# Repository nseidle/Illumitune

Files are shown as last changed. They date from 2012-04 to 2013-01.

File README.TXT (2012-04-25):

Illumitune is a exhibit at a kid's museum that has 8 infrared channels. When a channel is broken, a light turns on and a tone is played.

More information can be found at: http://www.sparkfun.com/tutorials/282

This repository contains all the firmware and design files for the various parts of the electronics. It also contains the logs from various dates. These logs show the usage information and are used for debugging and use trends.

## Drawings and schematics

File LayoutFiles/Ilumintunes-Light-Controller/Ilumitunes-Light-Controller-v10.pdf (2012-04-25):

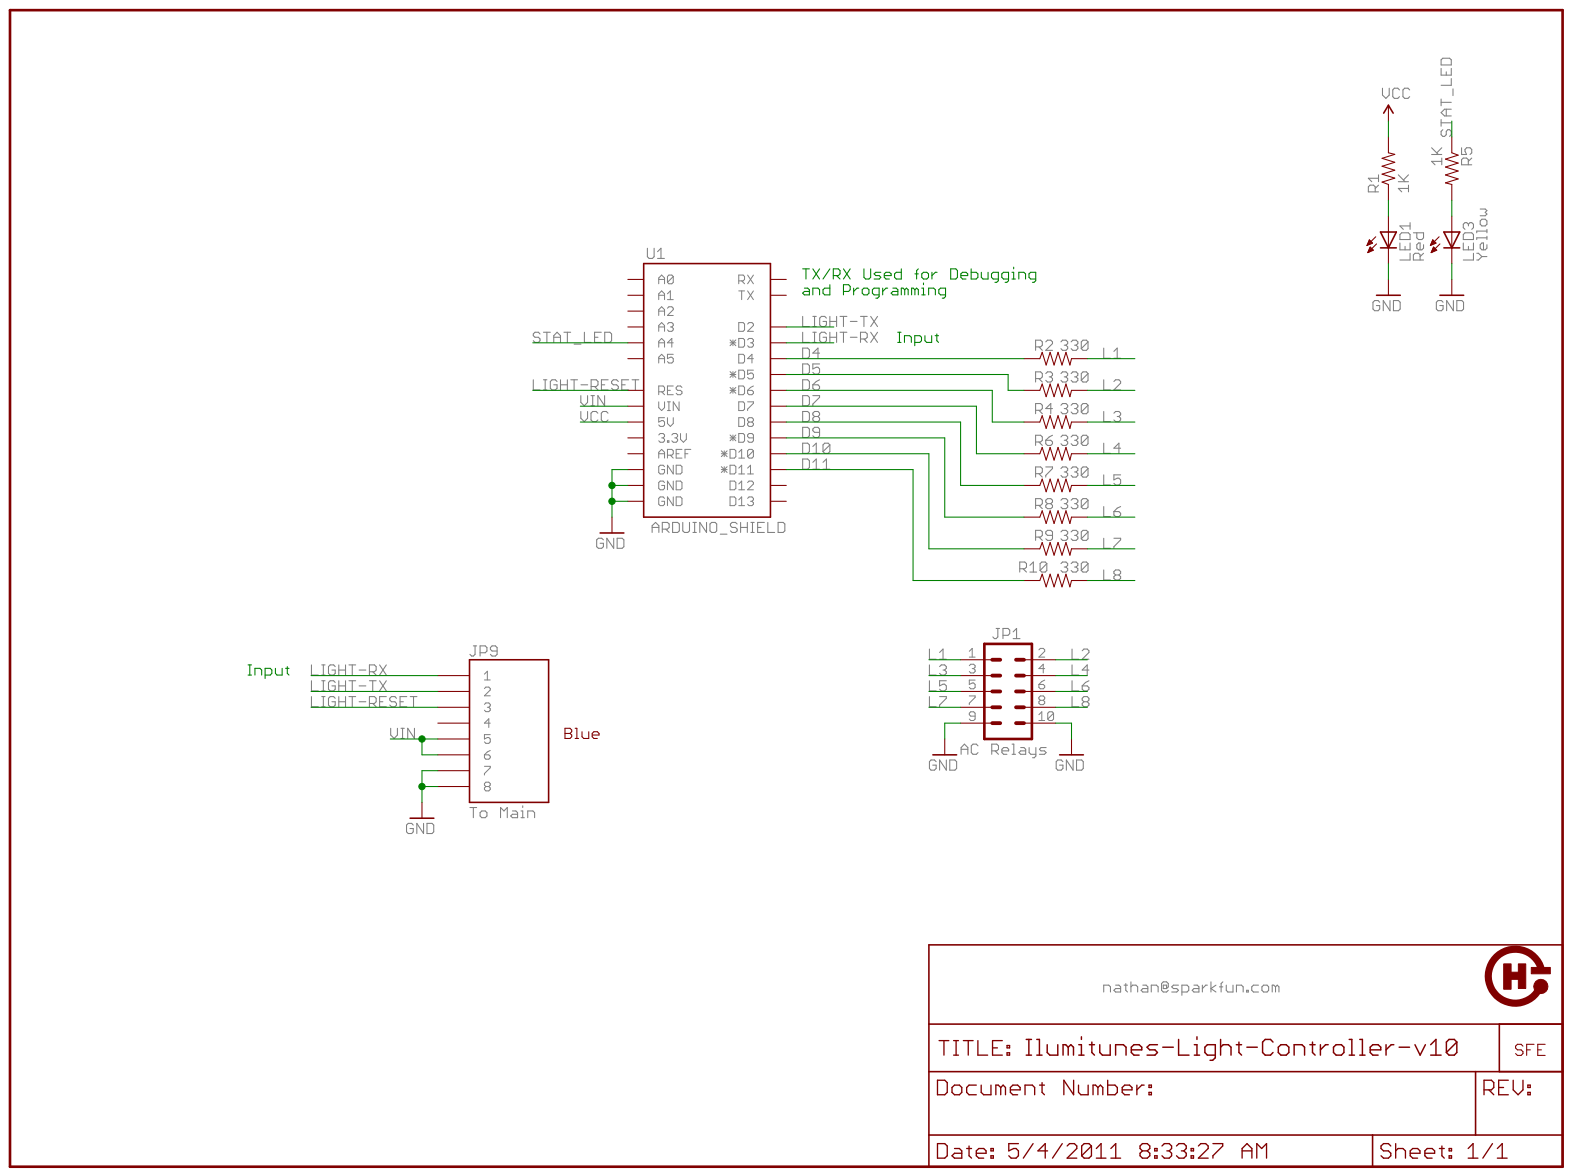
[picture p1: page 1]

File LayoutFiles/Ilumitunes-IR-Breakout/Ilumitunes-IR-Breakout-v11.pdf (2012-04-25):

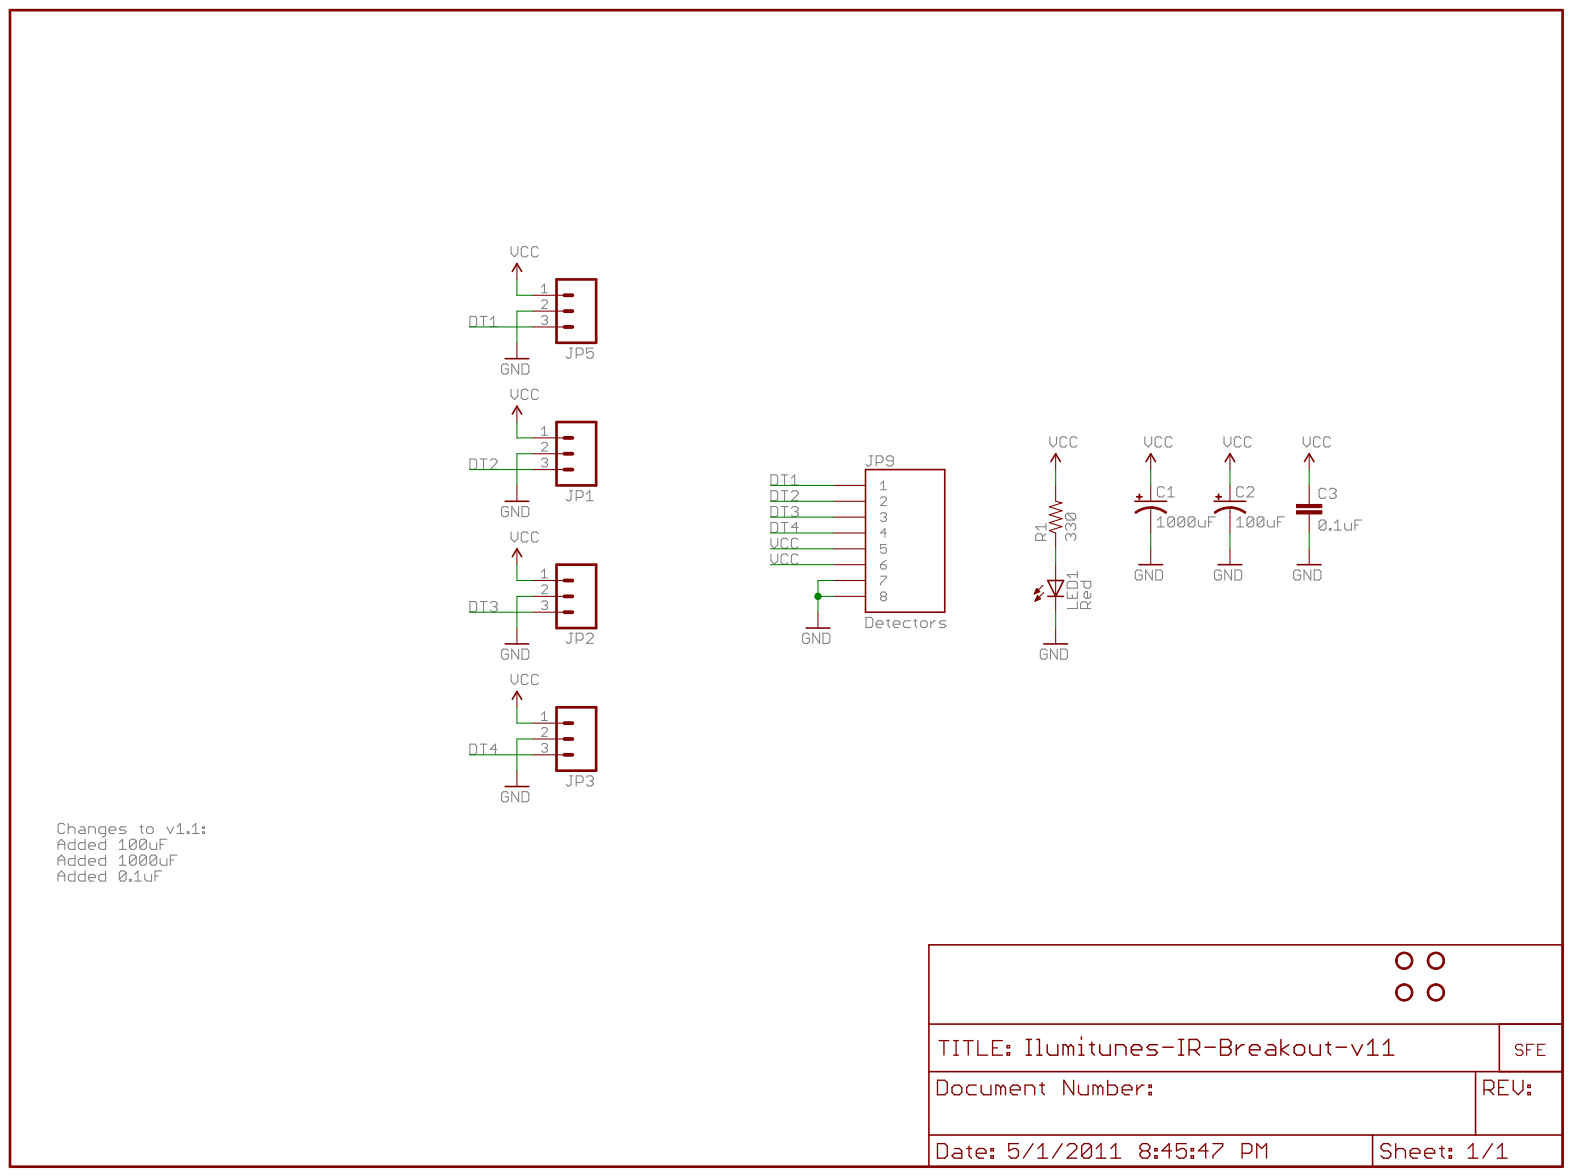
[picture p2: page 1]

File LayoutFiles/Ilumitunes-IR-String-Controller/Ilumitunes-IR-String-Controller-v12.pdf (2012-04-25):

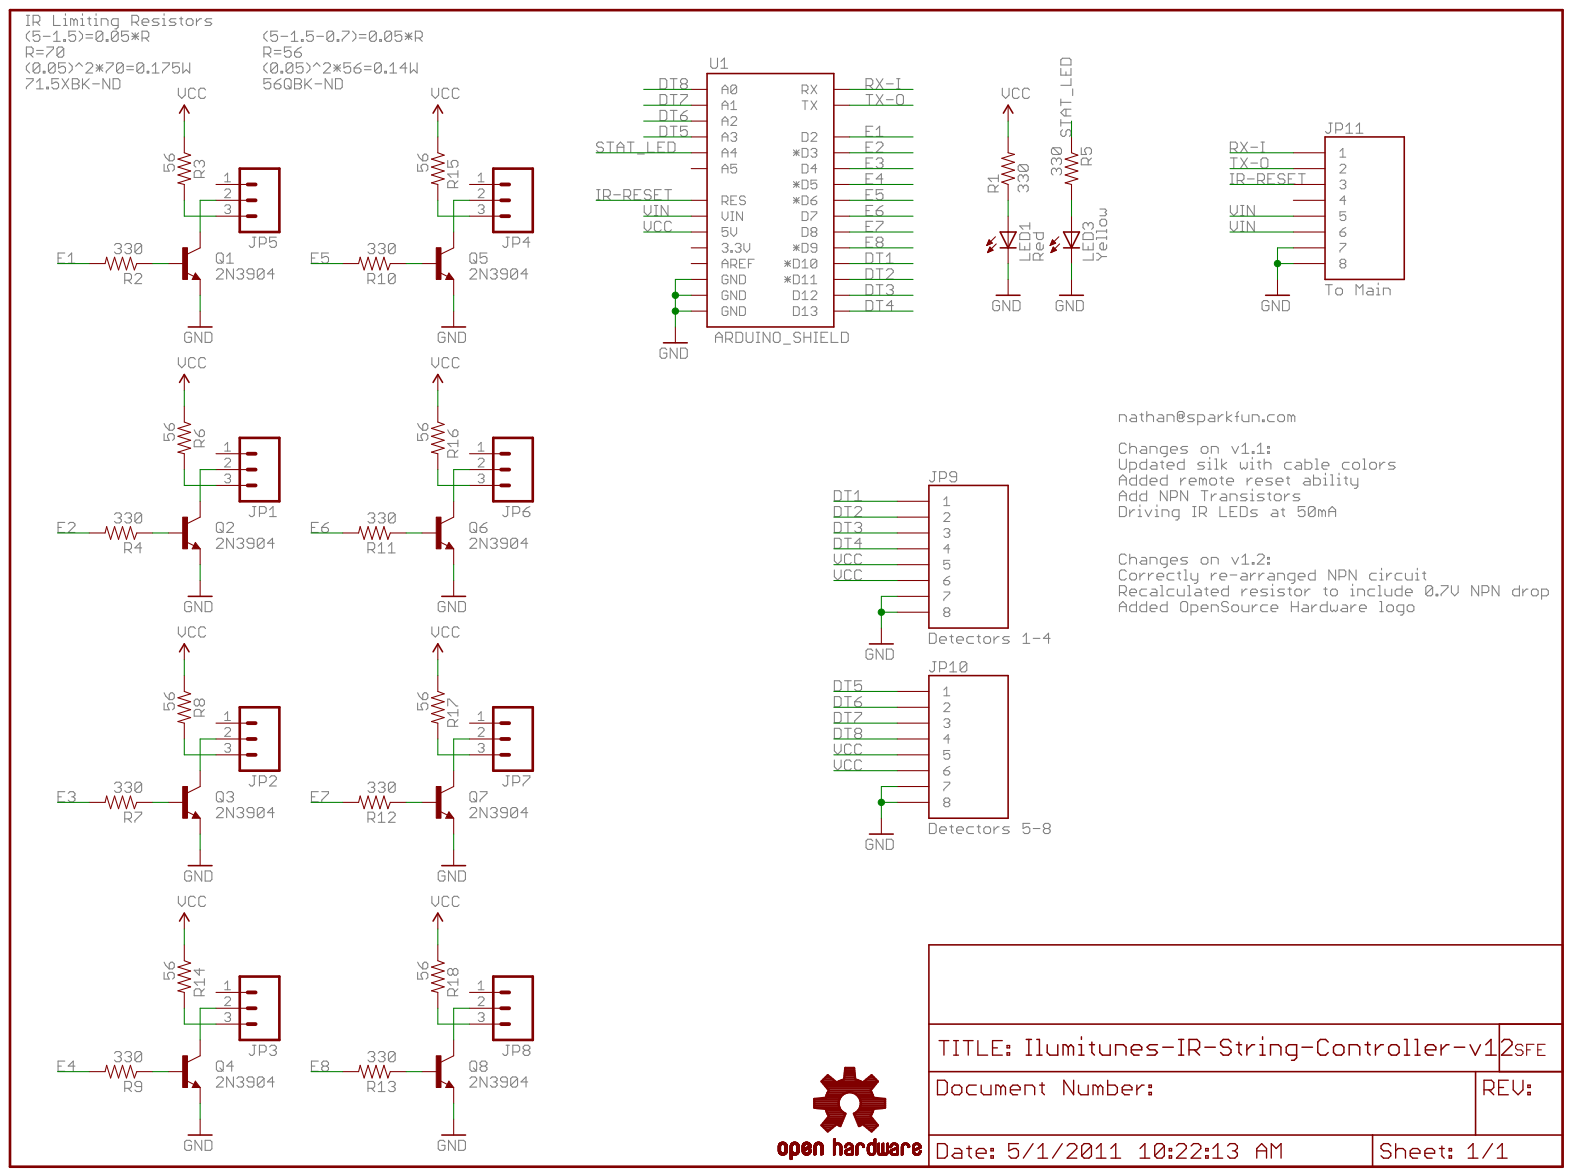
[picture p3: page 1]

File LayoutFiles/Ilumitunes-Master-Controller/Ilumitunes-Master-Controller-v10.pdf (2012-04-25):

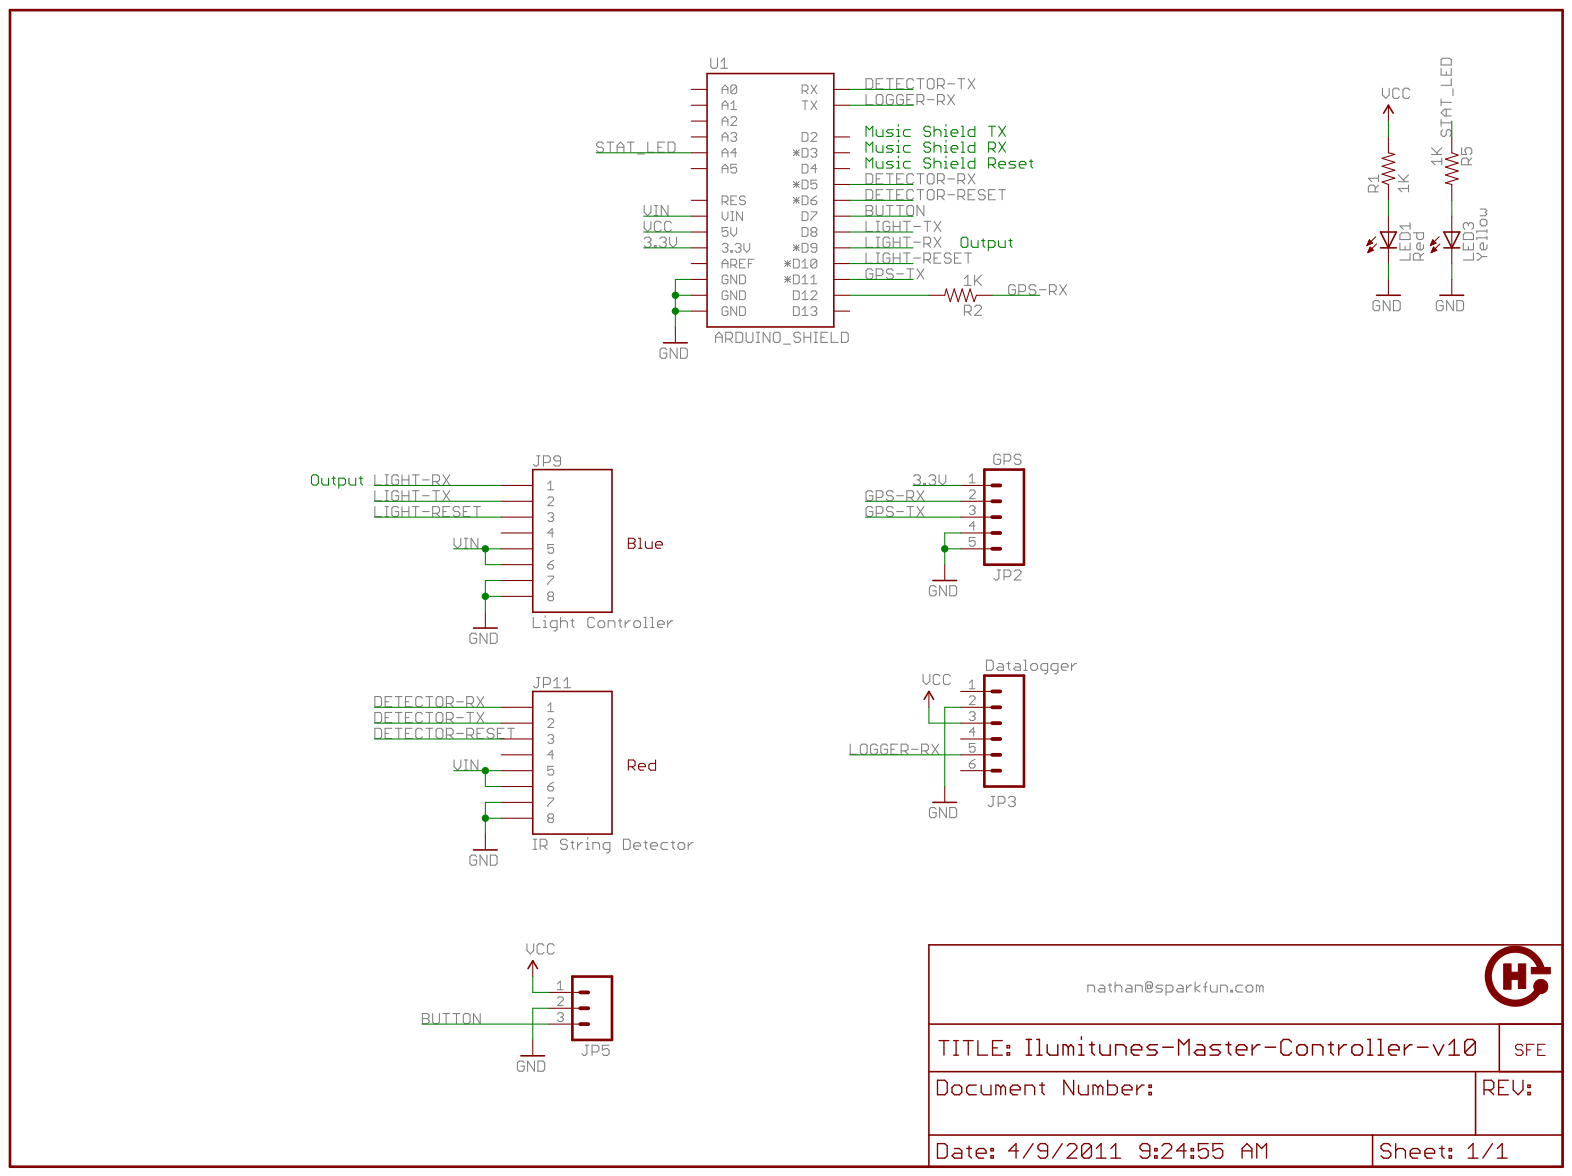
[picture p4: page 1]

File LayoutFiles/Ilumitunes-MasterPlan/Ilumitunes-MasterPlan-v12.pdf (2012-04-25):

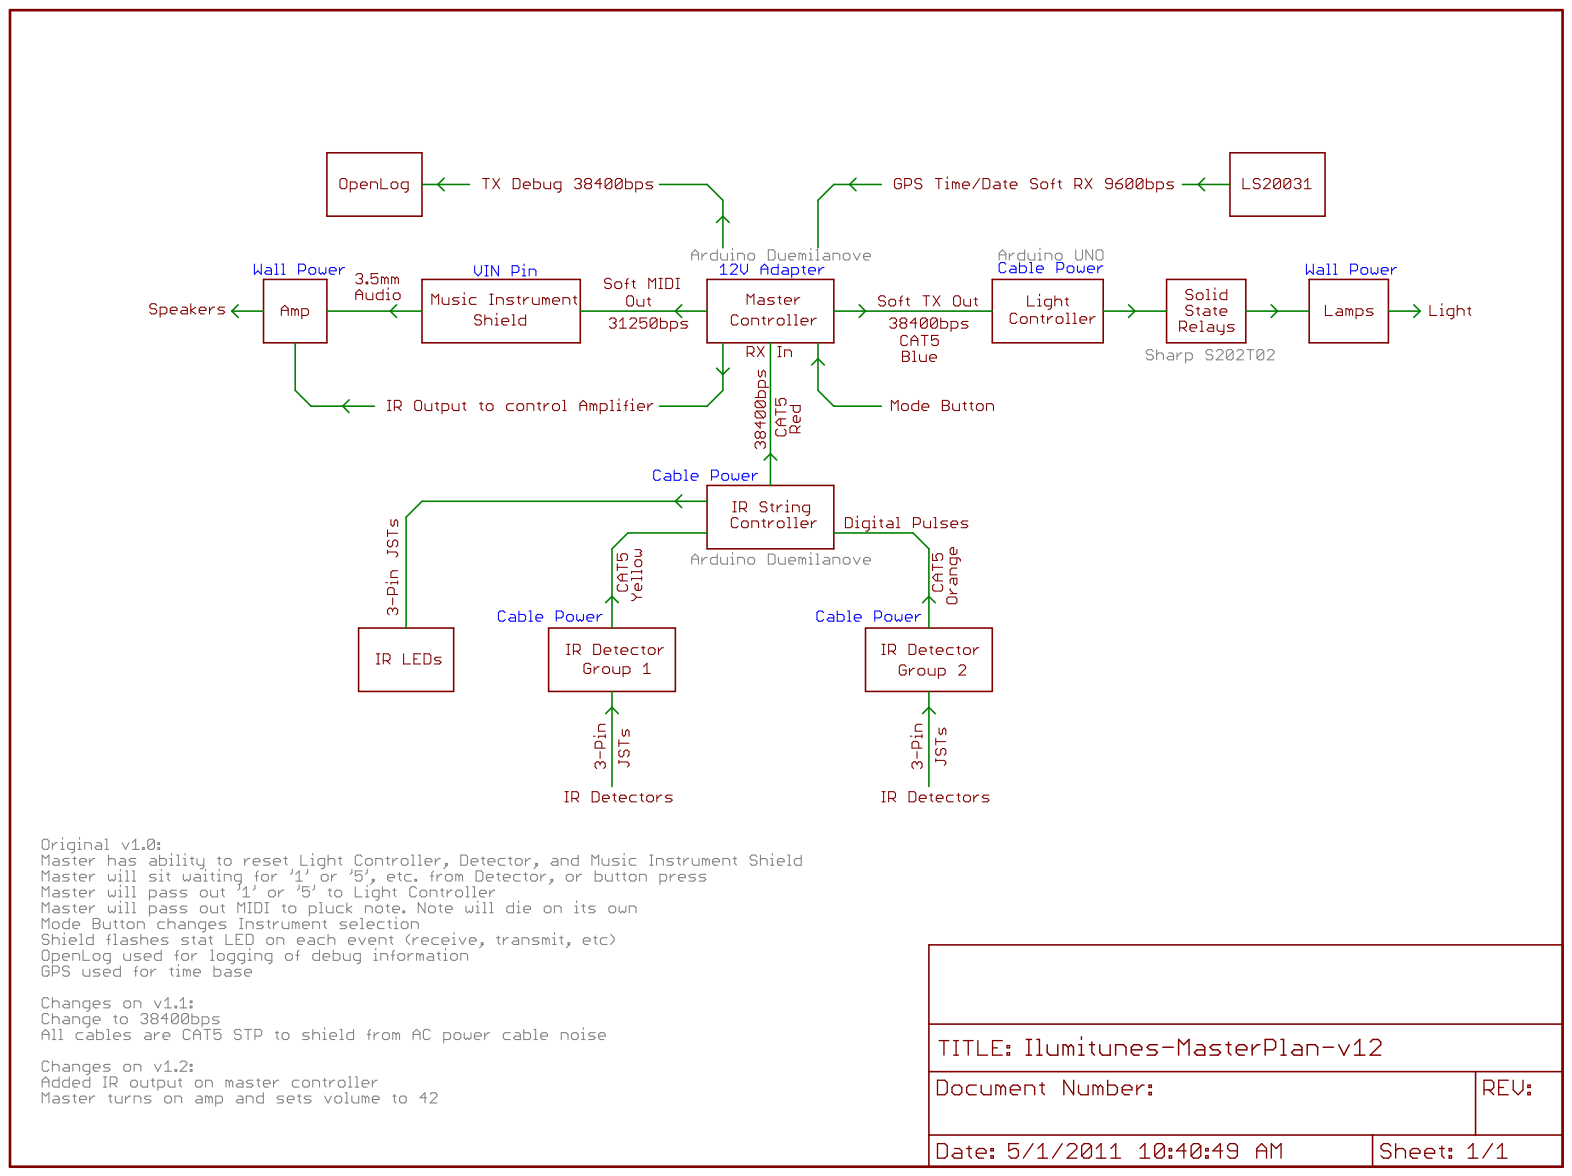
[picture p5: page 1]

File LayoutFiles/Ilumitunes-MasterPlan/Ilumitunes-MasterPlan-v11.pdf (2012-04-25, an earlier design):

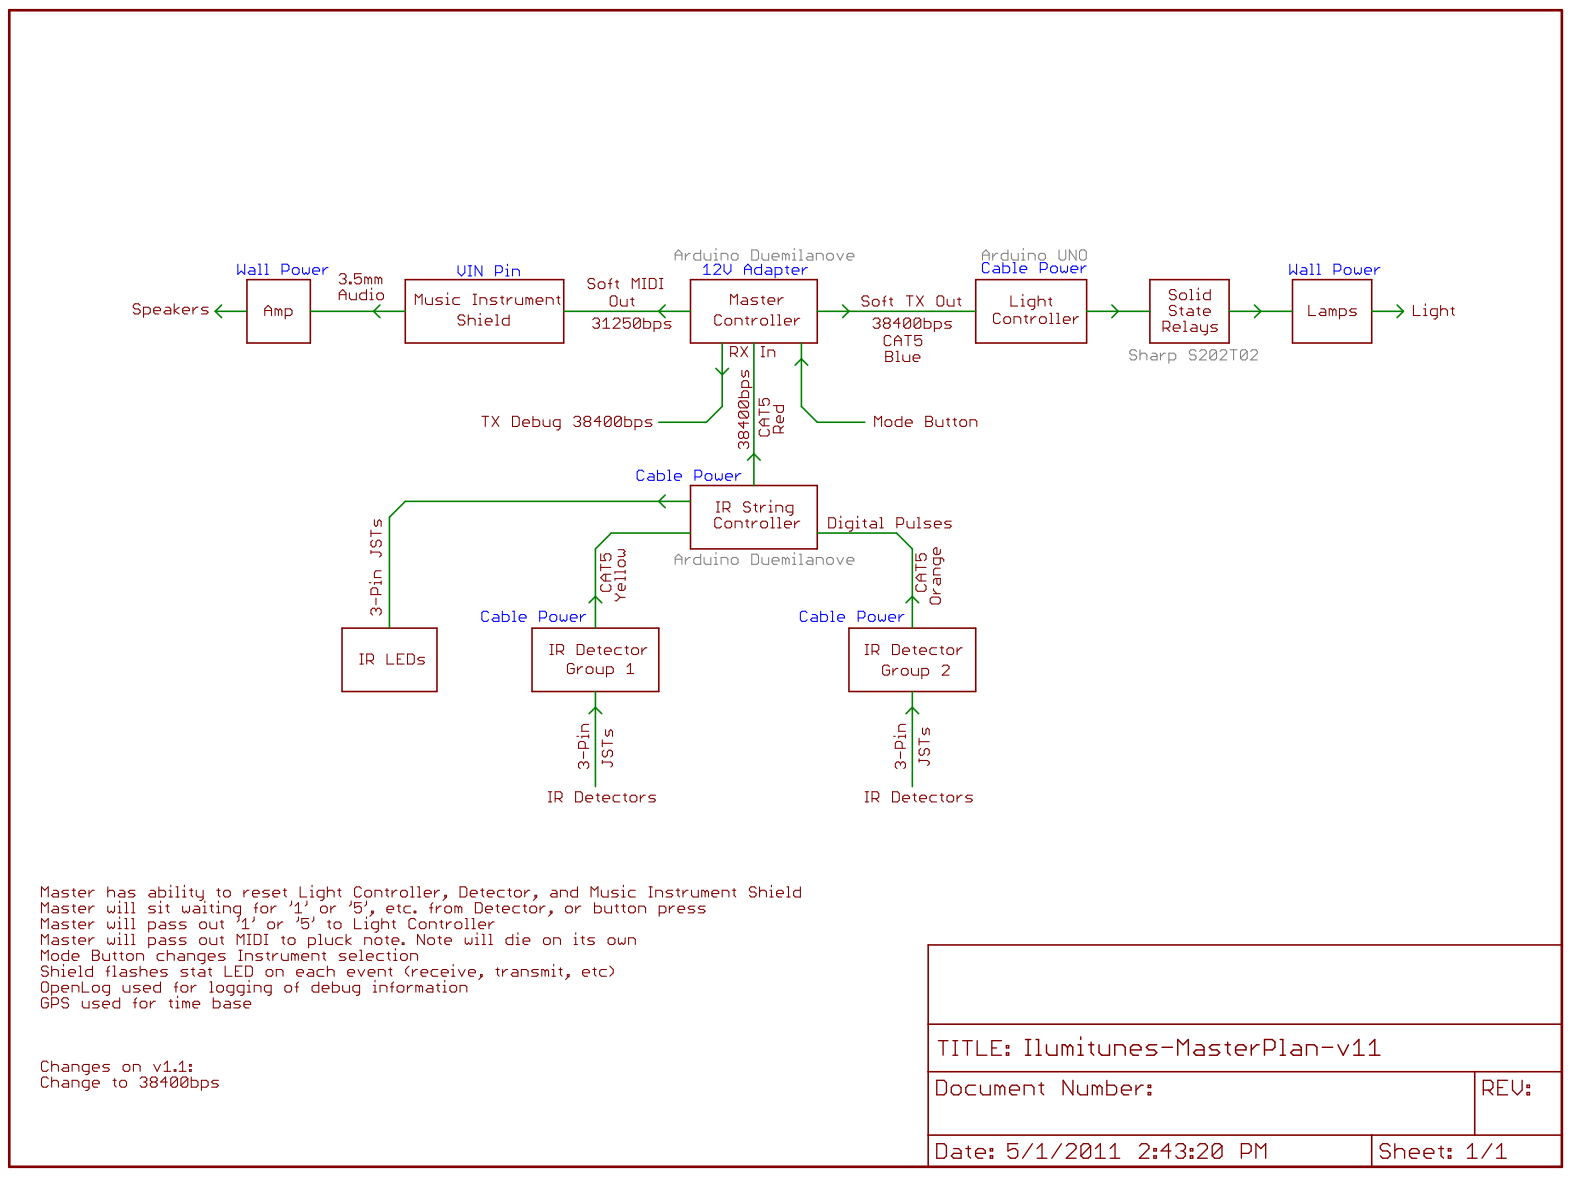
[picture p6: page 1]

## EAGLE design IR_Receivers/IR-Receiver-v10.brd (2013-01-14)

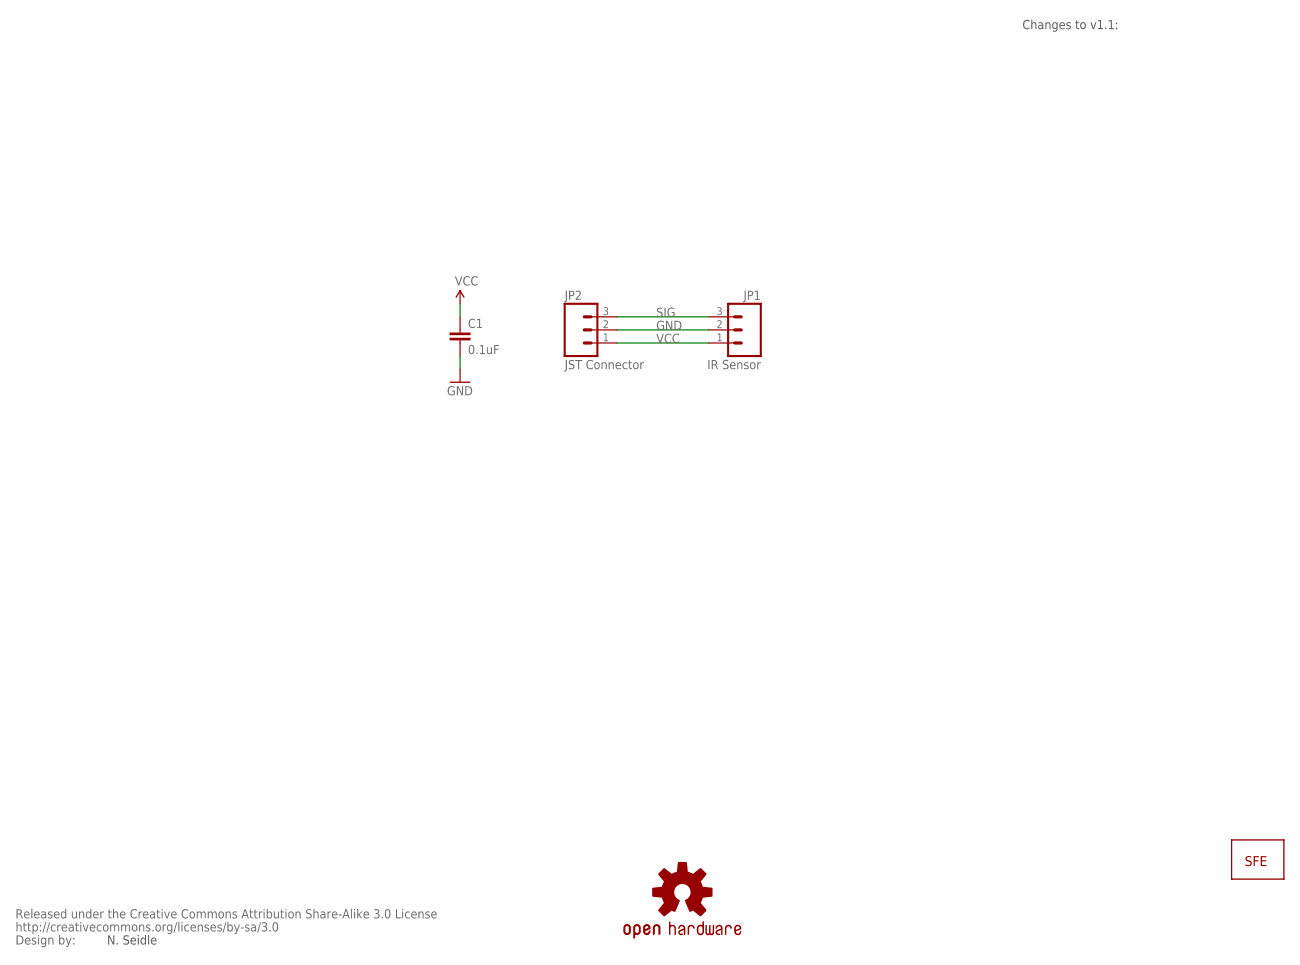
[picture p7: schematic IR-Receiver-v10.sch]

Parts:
C1: 0.1uF; CAP-PTH-SMALL2
JP1: IR Sensor; 1X03
JP2: JST Connector; JST-3-PTH
U$1: LOGO-SFESK; SFE-LOGO-FLAME
U$2: CREATIVE_COMMONS
U$4: OSHW-LOGOS; OSHW-LOGO-S

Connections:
GND: C1.2, JP1.2, JP2.2
SIG: JP1.3, JP2.3
VCC: C1.1, JP1.1, JP2.1

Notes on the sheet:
N. Seidle
Changes to v1.1:

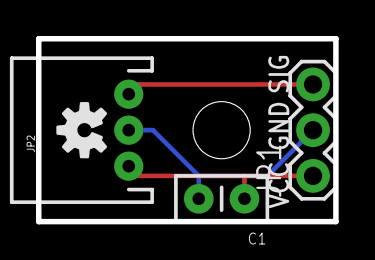
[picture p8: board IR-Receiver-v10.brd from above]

Board: 2 copper layers, 16.5 x 10.2 mm, 6 parts (1 on the bottom side), 3 nets.

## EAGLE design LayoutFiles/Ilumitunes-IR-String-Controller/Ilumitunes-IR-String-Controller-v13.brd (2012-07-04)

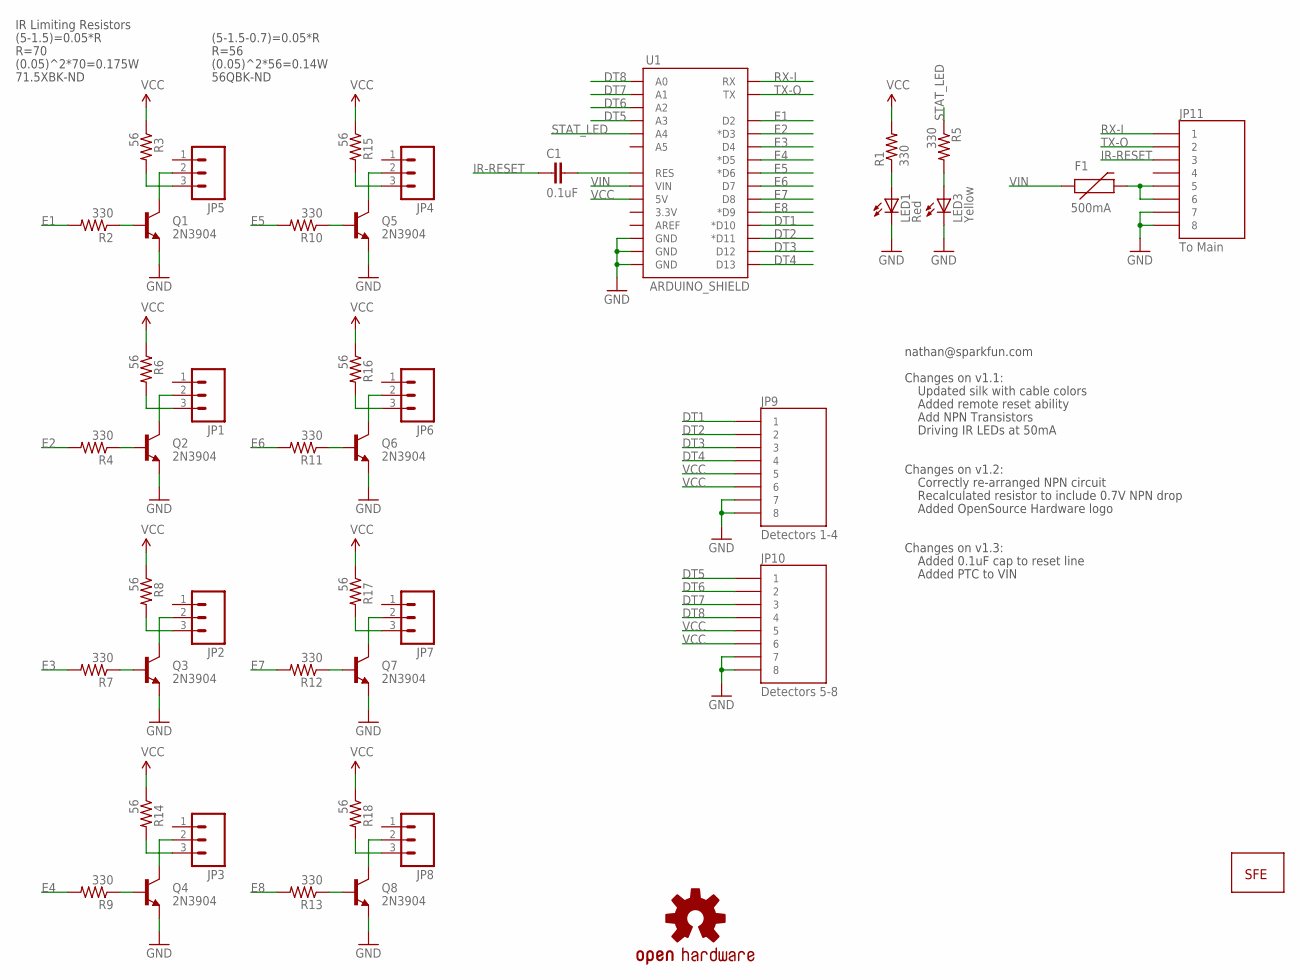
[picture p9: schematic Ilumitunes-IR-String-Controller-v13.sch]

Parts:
C1: 0.1uF; CAP-PTH-SMALL2
F1: 500mA; PTC
JP1, JP2, JP3, JP4, JP5, JP6, JP7, JP8: M03JST-PTH-VERT; JST-3-PTH-VERT
JP9: Detectors 1-4; RJ45-8
JP10: Detectors 5-8; RJ45-8
JP11: To Main; RJ45-8
LED1: Red; LED5MM
LED3: Yellow; LED5MM
Q1, Q2, Q3, Q4, Q5, Q6, Q7, Q8: 2N3904; TO-92
R1, R2, R4, R5, R7, R9, R10, R11, R12, R13: 330; AXIAL-0.3
R3, R6, R8, R14, R15, R16, R17, R18: 56; AXIAL-0.3
U1: ARDUINO_SHIELD; DUEMILANOVE_SHIELD_NOHOLES
U$1: LOGO-SFENEW; SFE-NEW-WEBLOGO
U$3: OSHW-LOGOS; OSHW-LOGO-S

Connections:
DT1: JP9.1, U1.D10 (*D10)
DT2: JP9.2, U1.D11 (*D11)
DT3: JP9.3, U1.D12
DT4: JP9.4, U1.D13
DT5: JP10.1, U1.A3
DT6: JP10.2, U1.A2
DT7: JP10.3, U1.A1
DT8: JP10.4, U1.A0
E1: R2.P$2 (2), U1.D2
E2: R4.P$2 (2), U1.D3 (*D3)
E3: R7.P$2 (2), U1.D4
E4: R9.P$2 (2), U1.D5 (*D5)
E5: R10.P$2 (2), U1.D6 (*D6)
E6: R11.P$2 (2), U1.D7
E7: R12.P$2 (2), U1.D8
E8: R13.P$2 (2), U1.D9 (*D9)
GND: JP9.7, JP9.8, JP10.7, JP10.8, JP11.7, JP11.8, LED1.K (C), LED3.K (C), Q1.1 (E), Q2.1 (E), Q3.1 (E), Q4.1 (E), Q5.1 (E), Q6.1 (E), Q7.1 (E), Q8.1 (E), U1.GND@0 (GND), U1.GND@1 (GND), U1.GND@2 (GND)
IR-RESET: C1.1, JP11.3
unnamed: LED1.A, R1.P$1 (1)
unnamed: Q1.2 (B), R2.P$1 (1)
unnamed: JP5.2, Q1.3 (C)
unnamed: LED3.A, R5.P$2 (2)
unnamed: JP5.3, R3.P$2 (2)
unnamed: JP1.2, Q2.3 (C)
unnamed: JP3.2, Q4.3 (C)
unnamed: JP8.2, Q8.3 (C)
unnamed: Q2.2 (B), R4.P$1 (1)
unnamed: JP1.3, R6.P$2 (2)
unnamed: Q3.2 (B), R7.P$1 (1)
unnamed: Q4.2 (B), R9.P$1 (1)
unnamed: Q6.2 (B), R11.P$1 (1)
unnamed: JP4.2, Q5.3 (C)
unnamed: JP6.3, R16.P$2 (2)
unnamed: Q7.2 (B), R12.P$1 (1)
unnamed: JP2.3, R8.P$2 (2)
unnamed: JP3.3, R14.P$2 (2)
unnamed: Q5.2 (B), R10.P$1 (1)
unnamed: C1.2, U1.RES
unnamed: JP4.3, R15.P$2 (2)
unnamed: JP6.2, Q6.3 (C)
unnamed: JP7.3, R17.P$2 (2)
unnamed: Q8.2 (B), R13.P$1 (1)
unnamed: JP7.2, Q7.3 (C)
unnamed: JP8.3, R18.P$2 (2)
unnamed: JP2.2, Q3.3 (C)
unnamed: F1.P$2 (2), JP11.5, JP11.6
RX-I: JP11.1, U1.RX
STAT_LED: R5.P$1 (1), U1.A4
TX-O: JP11.2, U1.TX
VCC: JP9.5, JP9.6, JP10.5, JP10.6, R1.P$2 (2), R3.P$1 (1), R6.P$1 (1), R8.P$1 (1), R14.P$1 (1), R15.P$1 (1), R16.P$1 (1), R17.P$1 (1), R18.P$1 (1), U1.5V
VIN: F1.P$1 (1), U1.VIN

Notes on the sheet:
Changes on v1.1:
Updated silk with cable colors
Added remote reset ability
nathan@sparkfun.com
Add NPN Transistors
(5-1.5)=0.05*R
R=70
(0.05)^2*70=0.175W
71.5XBK-ND
Driving IR LEDs at 50mA
IR Limiting Resistors
(5-1.5-0.7)=0.05*R
R=56
(0.05)^2*56=0.14W
56QBK-ND
Changes on v1.2:
Correctly re-arranged NPN circuit
Recalculated resistor to include 0.7V NPN drop
Added OpenSource Hardware logo
Changes on v1.3:
Added 0.1uF cap to reset line
Added PTC to VIN

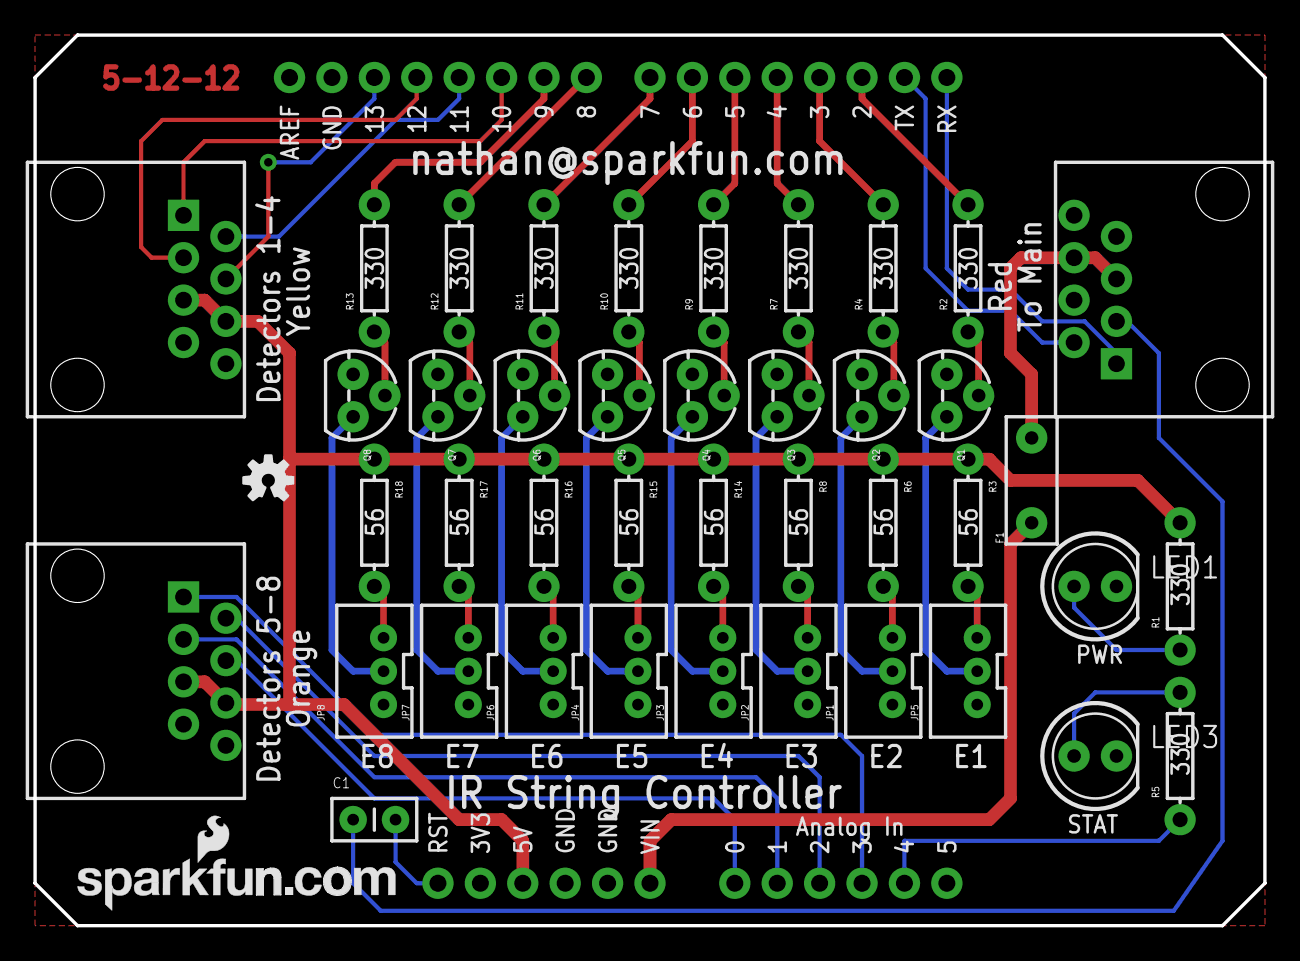
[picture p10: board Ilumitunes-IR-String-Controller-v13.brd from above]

Board: 2 copper layers, 73.7 x 53.3 mm, 44 parts (0 on the bottom side), 51 nets.

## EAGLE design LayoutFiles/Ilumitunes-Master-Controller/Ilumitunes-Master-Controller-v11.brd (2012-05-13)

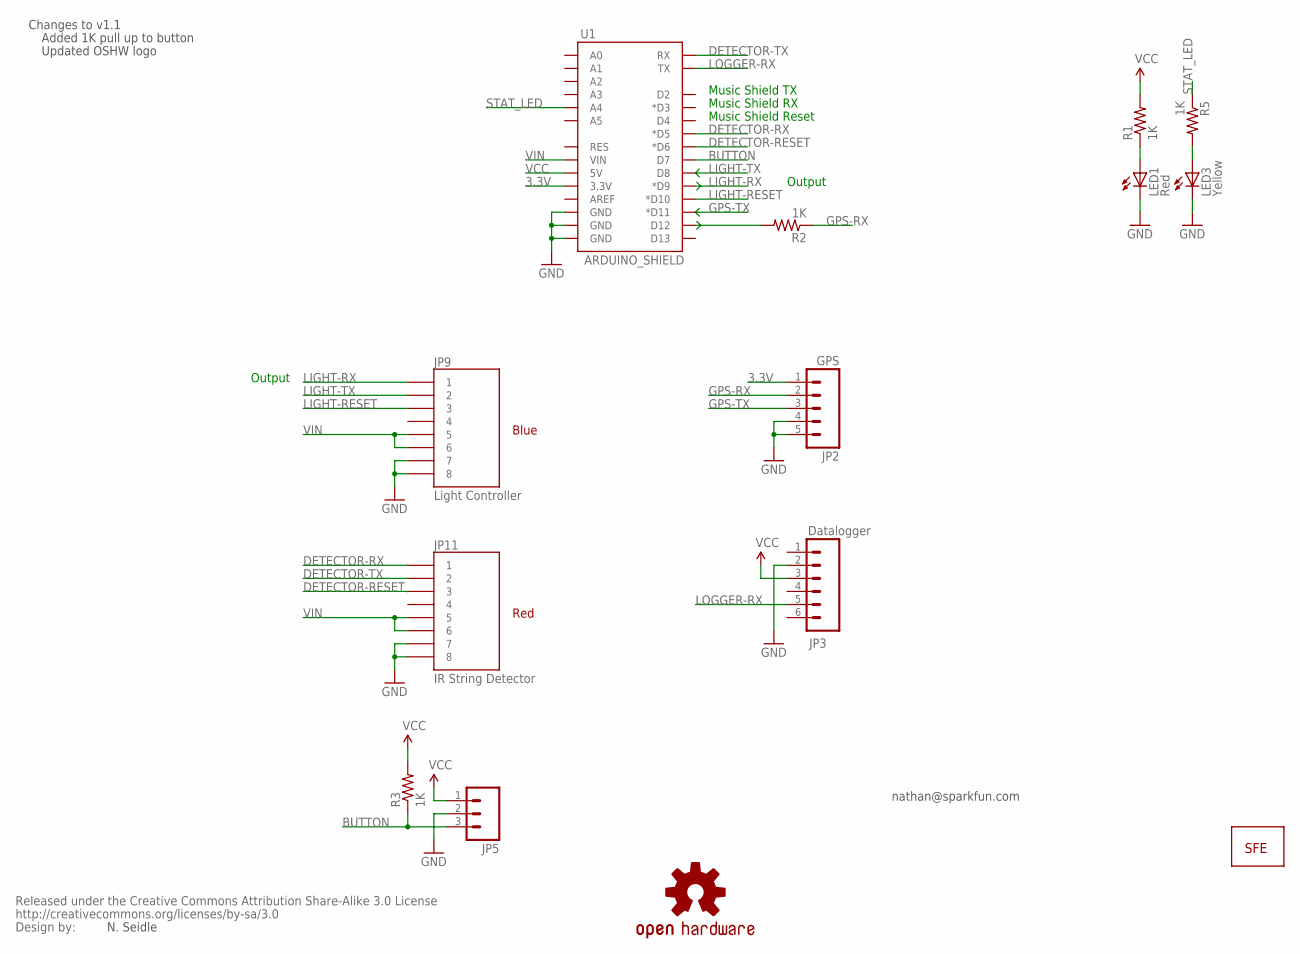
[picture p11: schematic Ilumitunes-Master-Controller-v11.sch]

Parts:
JP2: GPS; 1X05
JP3: Datalogger; 1X06
JP5: M03JST-PTH-VERT; JST-3-PTH-VERT
JP9: Light Controller; RJ45-8
JP11: IR String Detector; RJ45-8
LED1: Red; LED5MM
LED3: Yellow; LED5MM
R1, R2, R3, R5: 1K; AXIAL-0.3
U1: ARDUINO_SHIELD; DUEMILANOVE_SHIELD
U$1: LOGO-SFENEW; SFE-NEW-WEBLOGO
U$2: CREATIVE_COMMONS
U$3: OSHW-LOGOS; OSHW-LOGO-S

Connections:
3.3V: JP2.1, U1.3.3V
BUTTON: JP5.3, R3.P$1 (1), U1.D7
DETECTOR-RESET: JP11.3, U1.D6 (*D6)
DETECTOR-RX: JP11.1, U1.D5 (*D5)
DETECTOR-TX: JP11.2, U1.RX
GND: JP2.4, JP2.5, JP3.2, JP5.2, JP9.7, JP9.8, JP11.7, JP11.8, LED1.K (C), LED3.K (C), U1.GND@0 (GND), U1.GND@1 (GND), U1.GND@2 (GND)
GPS-RX: JP2.2, R2.P$1 (1)
GPS-TX: JP2.3, U1.D11 (*D11)
LIGHT-RESET: JP9.3, U1.D10 (*D10)
LIGHT-RX: JP9.1, U1.D9 (*D9)
LIGHT-TX: JP9.2, U1.D8
LOGGER-RX: JP3.5, U1.TX
unnamed: LED1.A, R1.P$1 (1)
unnamed: R2.P$2 (2), U1.D12
unnamed: LED3.A, R5.P$2 (2)
STAT_LED: R5.P$1 (1), U1.A4
VCC: JP3.3, JP5.1, R1.P$2 (2), R3.P$2 (2), U1.5V
VIN: JP9.5, JP9.6, JP11.5, JP11.6, U1.VIN

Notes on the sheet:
Music Shield RX
Music Shield Reset
Music Shield TX
Blue
Red
Output
nathan@sparkfun.com
Changes to v1.1
N. Seidle
Added 1K pull up to button
Updated OSHW logo

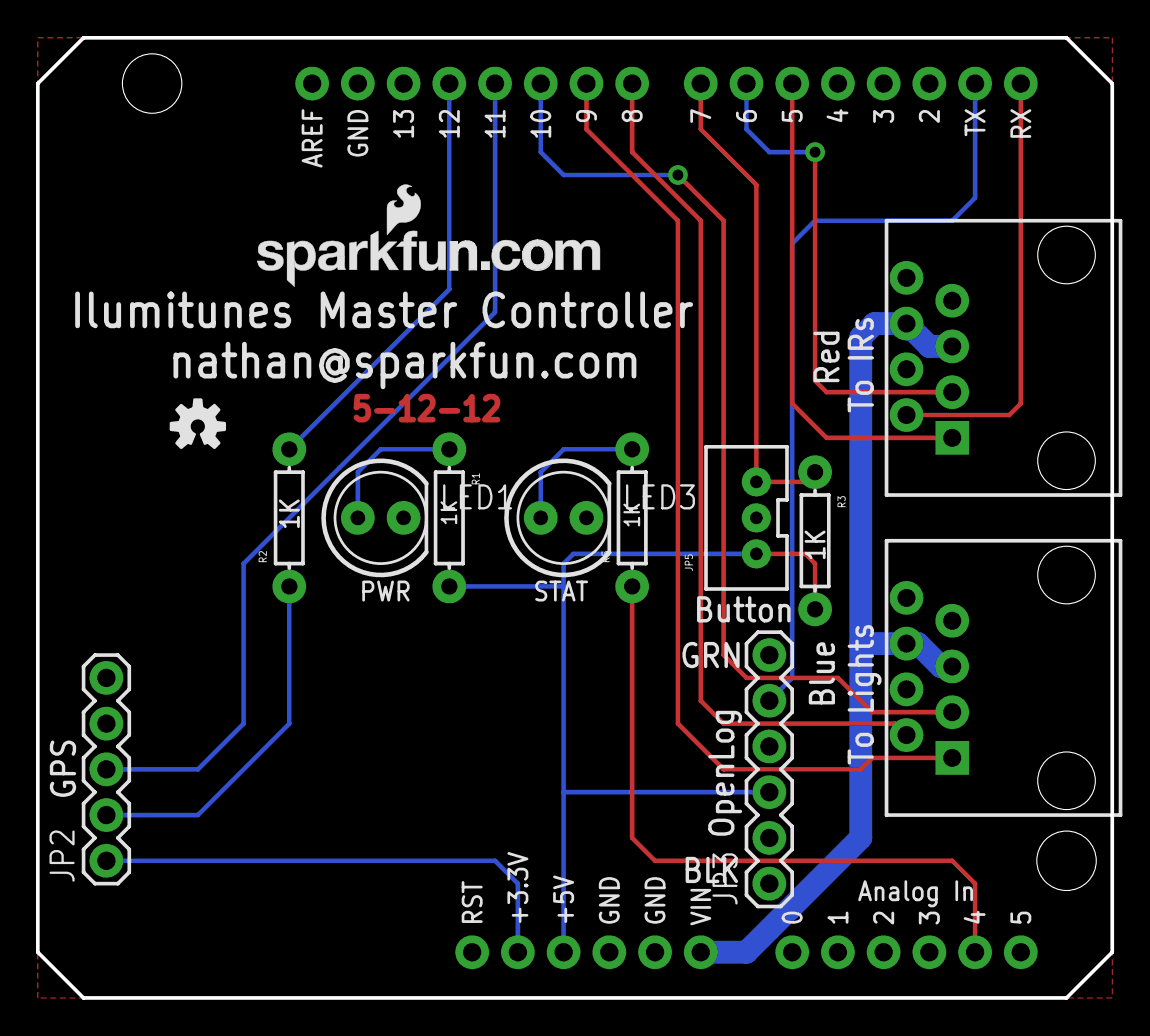
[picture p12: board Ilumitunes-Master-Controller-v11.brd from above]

Board: 2 copper layers, 59.7 x 53.3 mm, 15 parts (0 on the bottom side), 18 nets.

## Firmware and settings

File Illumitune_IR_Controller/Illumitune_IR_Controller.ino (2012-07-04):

/*
 3-30-2011
 Spark Fun Electronics 2011
 Nathan Seidle
 
 This code is public domain but you buy me a beer if you use this and we meet someday (Beerware license).

 IR is usually something like 40kHz
 
 Potentially build in an average so that if a sensor goes off line (unplugged), the system handles it well.
 
 Without a sensor attached, the system will 'give up' after MAXHITS (50) hits positive. This means that the system
 will begin to ignore a sensor that has run to a rail. But it will not ignore a sensor that is giving random readings.
 
 Gotcha: D13 can't be used as an input because there's a status LED on that pin. Ok for output, not ok for input.
 Removing the current limiting resistor on the main board fixed the problem.
 
 Everything now runs at 38400 because Arduino 21 and Uno don't play well at 38400bps.
 
 IR LEDs can be seen on most smart phone's camera. Use it to test the system!
 
 If a button gets hit more than 20 times in a row, disable it for X minutes? 
 
 From 4/9/11 trip to WOW, channel 4 is giving me fits. There may be an issue where we need to wait some time between 
 checking each channel? Trying to replicate the problem on my desk, tilting the IR receiver slightly out of alignment
 gives similar sorts of crazy output. Could it be an alignment issue? Check that the top IR LED is seated as low as 
 possible. Consider using channel-1 LED because that's a new/fresh LED.
 
 The output looks like: 
 35
 25
 18
 25
 19
 18
 14
 etc
 There must be a way average these and ignore anything less than MINIMUMHITS
 
 When I debug over USB, works great. When I power from main board, it activates 5/6 channels. Chaning the delay
 seems to help. Possibly check alternate channels instead of channels next to each other.
 
 possibly bring 5V USB wall wart to power board
 
 4/17/11: I found out that the lower AC power cords were causing havoc with the IR receivers. Today I replaced all
 the CAT5 cables with STP CAT5. It seems to help only a little. I also added 100uF and 1000uF caps to the IR receiver
 boards. But I still have two channels that are triggering oddly.
 
 Things to do: 
 Add IR out to main board to turn on the amplifier automatically. 
 More documentation on how to fix things if channel breaks (channel triggers on phantom).
 Build more IR LED strings to replace old LEDs.
 Modify more IR receivers.
 (done) Modify the Light controller code to work with new PCB.
 
 Possible IR issues:
 Top lens is dirty. Try removing it.
 Top LED is crooked. Add heat shrink to straighten it.
 Incoming IR signal is wacky. Add external 10k pull-ups. (I'm skipping this idea for now)
 Incoming IR signal is wacky. Bring DSO and look at power and signal lines.
 
 At home: Wait wait! The IR LEDs are being driven at 10mA with 330ohm resistor. Checking datasheet, they can be 
 run up to 50mA! Ahah! A quick test and LED runing at 20mA responds much better. I re-designed the IR controller 
 with NPNs and 71 ohm resistors to run LEDs at max 50mA. It will be a few weeks before I see new PCBs.
 
 I flip the firmware so that it reports 'success' of the IR beam. A larger number is shown when no hand is
 breaking beam.
 
 4-26-2011: Major breakthroughs. There was a bad timing issue in the channel test procedure. The code was written where channels
 7 and 8 where much slower than 1 and 2. With a logic analyzer, everything is the same now. Check wikipedia, looks like
 32 clicks is enough to get the channel to work correctly. It seems to be working very well tonight.
 
 4-25-2012:
 Update to Arduino v1.0. I have not yet pushed this new compiled code to the board.
 */

int irDetector1 = 10; //Left
int irDetector2 = 11; //Right
int irDetector3 = 12;
int irDetector4 = 13;
int irDetector5 = 17;//A3;
int irDetector6 = 16;//A2;
int irDetector7 = 15;//A1;
int irDetector8 = 14;//A0;

int irEmitter1 = 2;
int irEmitter2 = 3;
int irEmitter3 = 4;
int irEmitter4 = 5;
int irEmitter5 = 6;
int irEmitter6 = 7;
int irEmitter7 = 8;
int irEmitter8 = 9;

int StatusLED = A4;

int Hits[10]; //This array holds the number of times a channel is activated in a row
//We use this to disable a channel if it gets too many sequential 'hits'

int MAXHITS = 2; //This is the number of hits before a channel is ignored. 

//32 is the standard RC5 int NUMBEROFCHECKS = 32; //This is the number times we cycle a beam. 
int NUMBEROFCHECKS = 50; //This is the number times we cycle a beam. 
//Increasing this number slows down the system but helps prevent false positive breaks

//int MAXSEEN = 0; //This is the max number that we have to see to consider the beam broken
//Normally the IR detector will report NUMBEROFCHECKS as the number of hits. Any less than that means the beam
//is probably broken. However, I normally reduce the MINIMUMHITS by 5 so the system is a bit more robust

long ThisSecond = 0;

#define TRUE  0
#define FALSE  1
boolean AnnounceHits = FALSE;

void setup() {
  Serial.begin(38400);
  Serial.println("Illumitune IR String Controller v2.0"); 

  pinMode(StatusLED, OUTPUT);

  pinMode(irEmitter1, OUTPUT);
  pinMode(irEmitter2, OUTPUT);
  pinMode(irEmitter3, OUTPUT);
  pinMode(irEmitter4, OUTPUT);
  pinMode(irEmitter5, OUTPUT);
  pinMode(irEmitter6, OUTPUT);
  pinMode(irEmitter7, OUTPUT);
  pinMode(irEmitter8, OUTPUT);

  pinMode(irDetector1, INPUT);
  pinMode(irDetector2, INPUT);
  pinMode(irDetector3, INPUT);
  pinMode(irDetector4, INPUT);
  pinMode(irDetector5, INPUT);
  pinMode(irDetector6, INPUT);
  pinMode(irDetector7, INPUT);
  pinMode(irDetector8, INPUT);

  digitalWrite(irDetector1, HIGH);
  digitalWrite(irDetector2, HIGH);
  digitalWrite(irDetector3, HIGH);
  digitalWrite(irDetector4, HIGH);
  digitalWrite(irDetector5, HIGH);
  digitalWrite(irDetector6, HIGH);
  digitalWrite(irDetector7, HIGH);
  digitalWrite(irDetector8, HIGH);

  //LED max current testing
  /*while(1) {
   digitalWrite(irEmitter6, HIGH);
   digitalWrite(StatusLED, HIGH);
   delay(2000);
   
   digitalWrite(irEmitter6, LOW);
   digitalWrite(StatusLED, LOW);
   delay(2000);
   }*/

  //Turn on all the IR LEDs so that we can see what's going on from a smart phone
  demoIRLEDs();

  //This is a test routine that displays what the IRs are detecting
  //Do not call in production - it is an infinite loop
  //test_IRs();

  //Prefill the hits array - this was needed during testing
  for(int channel = 1 ; channel < 9 ; channel++)
    Hits[channel] = MAXHITS;

  //Let the world know we are online
  Serial.println("Channels indicate IR beam break");
}

void loop() {

  //Blink the status LED every second
  if( (millis()/1000) != ThisSecond) {
    ThisSecond = millis()/1000; //millis() will roll over every 50 days, but it should roll correctly
    if(digitalRead(StatusLED) == 0) 
      digitalWrite(StatusLED, HIGH);
    else
      digitalWrite(StatusLED, LOW);
  }

  //Test the beams
  for(int x = 1 ; x < 9 ; x++) {
    int channel = x;

    //Don't check two channels next to each other
    /*if(x == 1) channel = 1;
     if(x == 2) channel = 5;
     if(x == 3) channel = 2;
     if(x == 4) channel = 6;
     if(x == 5) channel = 3;
     if(x == 6) channel = 7;
     if(x == 7) channel = 4;
     if(x == 8) channel = 8;*/

    if(test_channel(channel) == 0) {
      //Record this hit
      Hits[channel]++;

      //Report this hit
      if(Hits[channel] < MAXHITS)
        AnnounceHits = TRUE; //We now need to report over serial once we're done testing the channels
      else
        Hits[channel] = MAXHITS; //This limits the size of hits to any given channel. Otherwise it'll wrap at 32,000 or there abouts after 30 seconds
    }
    else
      Hits[channel] = 0; //If we detect nothing, then reset the hits to this channel

    delay(1); //We have to have some amount of time in between IR flooding/checking, 1 to 5ms works well
  }

  //See if we have new channel hits to report over serial
  if(AnnounceHits == TRUE) {
    AnnounceHits = FALSE;

    //Wiggle the status LED
    if(digitalRead(StatusLED) == 0) 
      digitalWrite(StatusLED, HIGH);
    else
      digitalWrite(StatusLED, LOW);

    Serial.print("$");
    for(int channel = 1 ; channel < 9 ; channel++)
      if( (Hits[channel] < MAXHITS) && (Hits[channel] > 0) )  Serial.print(channel, DEC); //Report that this channel has been hit!
    Serial.print("#");
    Serial.println();
  }
}

//Tests a given IR channel to see if it is currently broken or clear
//Returns 1 if channel is clear
//Returns 0 if something is breaking the beam

//http://en.wikipedia.org/wiki/RC-5
//We need on for 8us, off for 20us
//We need 32 of these clicks, total of 889us
//Then a pause of 889us
//This will signify bit '1'

//For the illumitune we use 38kHz IR receivers, not 36kHz. Let's tweak to 38kHz.
//We need on for 8us, off for 20us
int test_channel(int channel_number) {

  for(int x = 0 ; x < NUMBEROFCHECKS ; x++) {

    switch(channel_number) {
      case(1): 
      digitalWrite(irEmitter1, HIGH); 
      break;
      case(2): 
      digitalWrite(irEmitter2, HIGH); 
      break;
      case(3): 
      digitalWrite(irEmitter3, HIGH); 
      break;
      case(4): 
      digitalWrite(irEmitter4, HIGH); 
      break;
      case(5): 
      digitalWrite(irEmitter5, HIGH); 
      break;
      case(6): 
      digitalWrite(irEmitter6, HIGH); 
      break;
      case(7): 
      digitalWrite(irEmitter7, HIGH); 
      break;
      case(8): 
      digitalWrite(irEmitter8, HIGH); 
      break;
    }

    //Delay exactly 7.8us, delayMicrosecond() doesn't work for this short of a delay
    __asm__("nop\n\t""nop\n\t""nop\n\t""nop\n\t""nop\n\t""nop\n\t""nop\n\t""nop\n\t""nop\n\t""nop\n\t");
    __asm__("nop\n\t""nop\n\t""nop\n\t""nop\n\t""nop\n\t""nop\n\t""nop\n\t""nop\n\t""nop\n\t""nop\n\t");
    __asm__("nop\n\t""nop\n\t""nop\n\t""nop\n\t""nop\n\t""nop\n\t""nop\n\t""nop\n\t""nop\n\t""nop\n\t");
    __asm__("nop\n\t""nop\n\t""nop\n\t""nop\n\t""nop\n\t""nop\n\t""nop\n\t""nop\n\t""nop\n\t""nop\n\t");
    __asm__("nop\n\t""nop\n\t""nop\n\t""nop\n\t");

    switch(channel_number) {
      case(1): 
      digitalWrite(irEmitter1, LOW); 
      break;
      case(2): 
      digitalWrite(irEmitter2, LOW); 
      break;
      case(3): 
      digitalWrite(irEmitter3, LOW); 
      break;
      case(4): 
      digitalWrite(irEmitter4, LOW); 
      break;
      case(5): 
      digitalWrite(irEmitter5, LOW); 
      break;
      case(6): 
      digitalWrite(irEmitter6, LOW); 
      break;
      case(7): 
      digitalWrite(irEmitter7, LOW); 
      break;
      case(8): 
      digitalWrite(irEmitter8, LOW); 
      break;
    }

    //Delay exactly 18.5us, delayMicrosecond() isn't accurate enough
    __asm__("nop\n\t""nop\n\t""nop\n\t""nop\n\t""nop\n\t""nop\n\t""nop\n\t""nop\n\t""nop\n\t""nop\n\t");
    __asm__("nop\n\t""nop\n\t""nop\n\t""nop\n\t""nop\n\t""nop\n\t""nop\n\t""nop\n\t""nop\n\t""nop\n\t");
    __asm__("nop\n\t""nop\n\t""nop\n\t""nop\n\t""nop\n\t""nop\n\t""nop\n\t""nop\n\t""nop\n\t""nop\n\t");
    __asm__("nop\n\t""nop\n\t""nop\n\t""nop\n\t""nop\n\t""nop\n\t""nop\n\t""nop\n\t""nop\n\t""nop\n\t");
    __asm__("nop\n\t""nop\n\t""nop\n\t""nop\n\t""nop\n\t""nop\n\t""nop\n\t""nop\n\t""nop\n\t""nop\n\t");
    __asm__("nop\n\t""nop\n\t""nop\n\t""nop\n\t""nop\n\t""nop\n\t""nop\n\t""nop\n\t""nop\n\t""nop\n\t");
    __asm__("nop\n\t""nop\n\t""nop\n\t""nop\n\t""nop\n\t""nop\n\t""nop\n\t""nop\n\t""nop\n\t""nop\n\t");
    __asm__("nop\n\t""nop\n\t""nop\n\t""nop\n\t""nop\n\t""nop\n\t""nop\n\t""nop\n\t""nop\n\t""nop\n\t");
    __asm__("nop\n\t""nop\n\t""nop\n\t""nop\n\t""nop\n\t""nop\n\t""nop\n\t""nop\n\t""nop\n\t""nop\n\t");
    __asm__("nop\n\t""nop\n\t""nop\n\t""nop\n\t""nop\n\t""nop\n\t""nop\n\t""nop\n\t""nop\n\t""nop\n\t");
    __asm__("nop\n\t""nop\n\t""nop\n\t""nop\n\t""nop\n\t""nop\n\t""nop\n\t""nop\n\t""nop\n\t""nop\n\t");
    __asm__("nop\n\t""nop\n\t""nop\n\t""nop\n\t""nop\n\t""nop\n\t""nop\n\t""nop\n\t""nop\n\t""nop\n\t");
    __asm__("nop\n\t""nop\n\t""nop\n\t""nop\n\t""nop\n\t""nop\n\t""nop\n\t""nop\n\t""nop\n\t""nop\n\t");
    __asm__("nop\n\t""nop\n\t""nop\n\t""nop\n\t""nop\n\t""nop\n\t""nop\n\t""nop\n\t""nop\n\t""nop\n\t");
    __asm__("nop\n\t""nop\n\t""nop\n\t""nop\n\t""nop\n\t""nop\n\t""nop\n\t""nop\n\t""nop\n\t""nop\n\t");
    __asm__("nop\n\t""nop\n\t""nop\n\t""nop\n\t""nop\n\t""nop\n\t""nop\n\t""nop\n\t""nop\n\t""nop\n\t");
    __asm__("nop\n\t""nop\n\t""nop\n\t""nop\n\t""nop\n\t""nop\n\t""nop\n\t""nop\n\t""nop\n\t""nop\n\t");
    __asm__("nop\n\t""nop\n\t""nop\n\t""nop\n\t""nop\n\t""nop\n\t""nop\n\t""nop\n\t""nop\n\t""nop\n\t");
    __asm__("nop\n\t""nop\n\t""nop\n\t""nop\n\t""nop\n\t""nop\n\t""nop\n\t""nop\n\t""nop\n\t""nop\n\t");
    __asm__("nop\n\t""nop\n\t""nop\n\t""nop\n\t""nop\n\t""nop\n\t""nop\n\t""nop\n\t""nop\n\t""nop\n\t");
    __asm__("nop\n\t""nop\n\t""nop\n\t");

  }

  if(channel_number == 1) 
    if(digitalRead(irDetector1) == HIGH) return(0); //Beam is broken!
  if(channel_number == 2) 
    if(digitalRead(irDetector2) == HIGH) return(0); //Beam is broken!
  if(channel_number == 3) 
    if(digitalRead(irDetector3) == HIGH) return(0); //Beam is broken!
  if(channel_number == 4) 
    if(digitalRead(irDetector4) == HIGH) return(0); //Beam is broken!
  if(channel_number == 5) 
    if(digitalRead(irDetector5) == HIGH) return(0); //Beam is broken!
  if(channel_number == 6) 
    if(digitalRead(irDetector6) == HIGH) return(0); //Beam is broken!
  if(channel_number == 7) 
    if(digitalRead(irDetector7) == HIGH) return(0); //Beam is broken!
  if(channel_number == 8) 
    if(digitalRead(irDetector8) == HIGH) return(0); //Beam is broken!

  return(1); //Beam is intact

}

//This routine helps debug a single channel
//It's an infinite loop. Don't call in production code
void test_IRs(void) {

  while(1) {
    Serial.print("Beams: ");

    for(int channel_number = 1 ; channel_number < 9 ; channel_number++) {

      for(int x = 0 ; x < NUMBEROFCHECKS ; x++) {

        switch(channel_number) {
          case(1): 
          digitalWrite(irEmitter1, HIGH); 
          break;
          case(2): 
          digitalWrite(irEmitter2, HIGH); 
          break;
          case(3): 
          digitalWrite(irEmitter3, HIGH); 
          break;
          case(4): 
          digitalWrite(irEmitter4, HIGH); 
          break;
          case(5): 
          digitalWrite(irEmitter5, HIGH); 
          break;
          case(6): 
          digitalWrite(irEmitter6, HIGH); 
          break;
          case(7): 
          digitalWrite(irEmitter7, HIGH); 
          break;
          case(8): 
          digitalWrite(irEmitter8, HIGH); 
          break;
        }

        //Delay exactly 7.8us, delayMicrosecond() doesn't work for this short of a delay
        __asm__("nop\n\t""nop\n\t""nop\n\t""nop\n\t""nop\n\t""nop\n\t""nop\n\t""nop\n\t""nop\n\t""nop\n\t");
        __asm__("nop\n\t""nop\n\t""nop\n\t""nop\n\t""nop\n\t""nop\n\t""nop\n\t""nop\n\t""nop\n\t""nop\n\t");
        __asm__("nop\n\t""nop\n\t""nop\n\t""nop\n\t""nop\n\t""nop\n\t""nop\n\t""nop\n\t""nop\n\t""nop\n\t");
        __asm__("nop\n\t""nop\n\t""nop\n\t""nop\n\t""nop\n\t""nop\n\t""nop\n\t""nop\n\t""nop\n\t""nop\n\t");
        __asm__("nop\n\t""nop\n\t""nop\n\t""nop\n\t");

        switch(channel_number) {
          case(1): 
          digitalWrite(irEmitter1, LOW); 
          break;
          case(2): 
          digitalWrite(irEmitter2, LOW); 
          break;
          case(3): 
          digitalWrite(irEmitter3, LOW); 
          break;
          case(4): 
          digitalWrite(irEmitter4, LOW); 
          break;
          case(5): 
          digitalWrite(irEmitter5, LOW); 
          break;
          case(6): 
          digitalWrite(irEmitter6, LOW); 
          break;
          case(7): 
          digitalWrite(irEmitter7, LOW); 
          break;
          case(8): 
          digitalWrite(irEmitter8, LOW); 
          break;
        }

        //Delay exactly 18.5us, delayMicrosecond() isn't accurate enough
        __asm__("nop\n\t""nop\n\t""nop\n\t""nop\n\t""nop\n\t""nop\n\t""nop\n\t""nop\n\t""nop\n\t""nop\n\t");
        __asm__("nop\n\t""nop\n\t""nop\n\t""nop\n\t""nop\n\t""nop\n\t""nop\n\t""nop\n\t""nop\n\t""nop\n\t");
        __asm__("nop\n\t""nop\n\t""nop\n\t""nop\n\t""nop\n\t""nop\n\t""nop\n\t""nop\n\t""nop\n\t""nop\n\t");
        __asm__("nop\n\t""nop\n\t""nop\n\t""nop\n\t""nop\n\t""nop\n\t""nop\n\t""nop\n\t""nop\n\t""nop\n\t");
        __asm__("nop\n\t""nop\n\t""nop\n\t""nop\n\t""nop\n\t""nop\n\t""nop\n\t""nop\n\t""nop\n\t""nop\n\t");
        __asm__("nop\n\t""nop\n\t""nop\n\t""nop\n\t""nop\n\t""nop\n\t""nop\n\t""nop\n\t""nop\n\t""nop\n\t");
        __asm__("nop\n\t""nop\n\t""nop\n\t""nop\n\t""nop\n\t""nop\n\t""nop\n\t""nop\n\t""nop\n\t""nop\n\t");
        __asm__("nop\n\t""nop\n\t""nop\n\t""nop\n\t""nop\n\t""nop\n\t""nop\n\t""nop\n\t""nop\n\t""nop\n\t");
        __asm__("nop\n\t""nop\n\t""nop\n\t""nop\n\t""nop\n\t""nop\n\t""nop\n\t""nop\n\t""nop\n\t""nop\n\t");
        __asm__("nop\n\t""nop\n\t""nop\n\t""nop\n\t""nop\n\t""nop\n\t""nop\n\t""nop\n\t""nop\n\t""nop\n\t");
        __asm__("nop\n\t""nop\n\t""nop\n\t""nop\n\t""nop\n\t""nop\n\t""nop\n\t""nop\n\t""nop\n\t""nop\n\t");
        __asm__("nop\n\t""nop\n\t""nop\n\t""nop\n\t""nop\n\t""nop\n\t""nop\n\t""nop\n\t""nop\n\t""nop\n\t");
        __asm__("nop\n\t""nop\n\t""nop\n\t""nop\n\t""nop\n\t""nop\n\t""nop\n\t""nop\n\t""nop\n\t""nop\n\t");
        __asm__("nop\n\t""nop\n\t""nop\n\t""nop\n\t""nop\n\t""nop\n\t""nop\n\t""nop\n\t""nop\n\t""nop\n\t");
        __asm__("nop\n\t""nop\n\t""nop\n\t""nop\n\t""nop\n\t""nop\n\t""nop\n\t""nop\n\t""nop\n\t""nop\n\t");
        __asm__("nop\n\t""nop\n\t""nop\n\t""nop\n\t""nop\n\t""nop\n\t""nop\n\t""nop\n\t""nop\n\t""nop\n\t");
        __asm__("nop\n\t""nop\n\t""nop\n\t""nop\n\t""nop\n\t""nop\n\t""nop\n\t""nop\n\t""nop\n\t""nop\n\t");
        __asm__("nop\n\t""nop\n\t""nop\n\t""nop\n\t""nop\n\t""nop\n\t""nop\n\t""nop\n\t""nop\n\t""nop\n\t");
        __asm__("nop\n\t""nop\n\t""nop\n\t""nop\n\t""nop\n\t""nop\n\t""nop\n\t""nop\n\t""nop\n\t""nop\n\t");
        __asm__("nop\n\t""nop\n\t""nop\n\t""nop\n\t""nop\n\t""nop\n\t""nop\n\t""nop\n\t""nop\n\t""nop\n\t");
        __asm__("nop\n\t""nop\n\t""nop\n\t");

      }

      //Show what we found
      Serial.print(channel_number, DEC);
      Serial.print(":");

      if(channel_number == 1)
        if(digitalRead(irDetector1) == HIGH) 
          Serial.print("--");
        else
          Serial.print("00");
      if(channel_number == 2)
        if(digitalRead(irDetector2) == HIGH) 
          Serial.print("--");
        else
          Serial.print("00");
      if(channel_number == 3)
        if(digitalRead(irDetector3) == HIGH) 
          Serial.print("--");
        else
          Serial.print("00");
      if(channel_number == 4)
        if(digitalRead(irDetector4) == HIGH) 
          Serial.print("--");
        else
          Serial.print("00");
      if(channel_number == 5)
        if(digitalRead(irDetector5) == HIGH) 
          Serial.print("--");
        else
          Serial.print("00");
      if(channel_number == 6)
        if(digitalRead(irDetector6) == HIGH) 
          Serial.print("--");
        else
          Serial.print("00");
      if(channel_number == 7)
        if(digitalRead(irDetector7) == HIGH) 
          Serial.print("--");
        else
          Serial.print("00");
      if(channel_number == 8)
        if(digitalRead(irDetector8) == HIGH) 
          Serial.print("--");
        else
          Serial.print("00");

      Serial.print(" ");
    }
    Serial.println();
    
    //delay(10);
  }
}

#define ON HIGH
#define OFF LOW
void demoIRLEDs(void) {
  Serial.println("IRs are demoing - break out your smart phone to see");

  //Turn on all LEDs
  digitalWrite(irEmitter1, ON);
  digitalWrite(irEmitter2, ON);
  digitalWrite(irEmitter3, ON);
  digitalWrite(irEmitter4, ON);
  digitalWrite(irEmitter5, ON);
  digitalWrite(irEmitter6, ON);
  digitalWrite(irEmitter7, ON);
  digitalWrite(irEmitter8, ON);

  //Use this to turn the LEDs on permanently so that you can inspect each one with a smart phone
  //Serial.println("LEDs always on");
  //while(1);
  delay(1000);

  //Turn off all LEDs
  digitalWrite(irEmitter1, OFF);
  digitalWrite(irEmitter2, OFF);
  digitalWrite(irEmitter3, OFF);
  digitalWrite(irEmitter4, OFF);
  digitalWrite(irEmitter5, OFF);
  digitalWrite(irEmitter6, OFF);
  digitalWrite(irEmitter7, OFF);
  digitalWrite(irEmitter8, OFF);

  //Turn on one LED to verify the channel is under control
  //digitalWrite(irEmitter4, ON);
  //while(1);

  //This is only for debug! Do not uncomment

  //Toggle each LED
  /*
#define QUICKWAIT  1000
   while(1) { //Infinite loop so that you can see the LEDs under individual control
   digitalWrite(irEmitter1, ON);
   delay(QUICKWAIT);
   digitalWrite(irEmitter1, OFF);
   
   digitalWrite(irEmitter2, ON);
   delay(QUICKWAIT);
   digitalWrite(irEmitter2, OFF);
   
   digitalWrite(irEmitter3, ON);
   delay(QUICKWAIT);
   digitalWrite(irEmitter3, OFF);
   
   digitalWrite(irEmitter4, ON);
   delay(QUICKWAIT);
   digitalWrite(irEmitter4, OFF);
   
   digitalWrite(irEmitter5, ON);
   delay(QUICKWAIT);
   digitalWrite(irEmitter5, OFF);
   
   digitalWrite(irEmitter6, ON);
   delay(QUICKWAIT);
   digitalWrite(irEmitter6, OFF);
   
   digitalWrite(irEmitter7, ON);
   delay(QUICKWAIT);
   digitalWrite(irEmitter7, OFF);
   
   digitalWrite(irEmitter8, ON);
   delay(QUICKWAIT);
   digitalWrite(irEmitter8, OFF);
   }
   */
}

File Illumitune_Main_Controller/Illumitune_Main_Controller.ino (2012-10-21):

/*
 3-30-2011
 Spark Fun Electronics 2011
 Nathan Seidle
 
 This code is public domain but you buy me a beer if you use this and we meet someday (Beerware license).
 
 The harp mainboard takes in serial commands from the IR sensors and a button. When $34# comes in, musical
 instruments 3 and 4 are played once. Not twice. When the button is pressed, the array of instruments is changed.
 
 Everything now runs at 38400 because Arduino 21 and Uno don't play well at 38400bps.
 
 Things to do:
 1) We may want to build a watch dog into the main board and the peripheral boards. Added 8/3/11
 
 2) We may want to build in a 'play with me function' where the unit starts making noise if people don't use it after
 a certain amount of time. Done 4/11/11
 
 3) We should play a note every time the button is hit. Done 4/10/11
 
 4) Enable remote reset of boards. Done 4/11/11
 
 5) Add IR output from the main board so that we can turn on the amplifier without having to open the side panel. Done 4/24/11
 
 4-13-2011: Fixed a bad bug with the incomingIRs array and incomingSpot variable getting too big. Moved everything to 115200bps.
 We need to test and then set the screen saver timeout
 
 4-24-2011: Added IR control of stereo.
 
 Good sounds: 
 
 Piano - plays notes 70 to 78
 Bank 0x00
 0
 6
 14
 75
 80
 91
 113
 115
 118
 124
 
 Fancy sounds, just one note each
 Bank 0x78
 30, 41, 49, 55, 58, 60, 66, 72, 78
 
 Instrument
 6
 8
 9
 19
 85
 91
 98
 104
 
 4-27-2011: Adding IR control of audio amp.
 Power:    0xC1A28877
 Standby:  0xC1A2B847
 Vol up:   0xC1A2E21D
 Vol down: 0xC1A2D22D
 
 7-27-2011: Employees are reporting that Illumitune is making loud noises,
 usually in the afternoon. I get differing reports of what fixes it, hitting the
 button? Or unplugging it? Does it occur more often after long periods of inactivity?
 
 Is it an old version of the MIDI shield that is going haywire? It is the old version,
 replace with new 1k inline version. We'll need to add IR and cut a trace.
 Modifications: Cut trace on MIS, pin 3 now goes to IR
 Add JST
 Add current resistor to IR
 Green wire to pin 5? That is now Soft TX out to the MIS. Why? Conflicted with IR control
 
 Is it the main controller going into the weeds?
 What happens if we have the main controller go into reset, will the
 IO pins high impedance cause the MIS to go noisy?
 Perhaps we can reset the MIS after every 10 mins of inactivity?
 
 Ahah! Any time resetMIDI goes low, VS1053 outputs white noise. This happens if ATmega goes into the weeds.
 We need a watch dog timer. After some research, WatchDog seems to not work on old ATmega328 duelminova boards. 
 May need Uno? Let's leave illumitune without WD, but let's never pull MIDIreset low.
 
 Need to change main so that it does not report the 'screen saver' to log every time - Fixed
 After initial boot up the scale sounds very wrong. Why? - Fixed
 
 Pulled logs as well
 
 8-3-2011: Installing new MIS.
 Watchdog works but acts a bit funny. Adding more information to logging so we know at what point
 the unit reset. 
 
 Pulled the logs. I can see where the unit is powered up/down during the day...
 
 Pulled the green LED light from channel 4(?).
 The bulb type seems to be:
 JDR Type GU-10 Base / MR16 2 Diameter / Line Voltage / 20 Watt
 The original green lamp had 21LEDs, and a very slight convex lens.
 Search for: MR16 GU-10 Green LED
 About the only place I could find one is here:
 http://www.bulbamerica.com/silver-1w-mr16-18led-gu10-base-green-bulb.html
 
 10-12-2011
 More reports of bad feedback.
 
 Pulling the logs, it looks like the unit resets after switching instruments.
 
 To see how long reset takes, we need to add a print time after the unit is up.
 
 It would also be good to correctly mark the LOG file date
 
 Whoa! Holding the instrument button causes system reset!
 Now the dog is pet while the button is held.
 
 Now something is wrong with the GPS parsing? The petDog function was printing so much
 ths GPS parser couldn't catch up.
 
 The unit seems to be WDT resetting on notes as well. Weird. I added more petting in more loops. 
 
 11-17-2011
 More reports of bad feedback. Came in at 9AM and the unit was working but making no noise? After a reset the unit starts working
 as expected.
 
 Logs show weird time stamps and often stopping logging after pressing a button. Why?
 Time stamps are working fine, but there are no more WDT resets in the logs. Dah?
 
 Why is there a BUNCH of button hits before the end of some logs? I installed a 1k pull up on the button input pin.
 
 12-14-2011
 On the last visit I installed the new RC block on the MIDI shield. There are still reports of the bad feedback noise. On this visit,
 the unit was completely down and has been for a few days. This time it was the instrument button that had jammed shut. This
 caused the system to hang infinitely.
 
 Programming in a button state so that the system does not hang.
 
 Need to bring a new button and graphite lube next time. The blue LED light is also out.
 
 3-20-2012
 Bringing new switches. Updating to Arduino v1.0.
 
 Added two new spots (spot++ check and buttonPresses check) where we may get a variable over-run.
 
 Replacing blue bulb with white bulb.
 Checking why channel 8 (purple, last channel) is not working.
 
 Adding ability to disable GPS parsing. Could this library be responsible for failure? I am going to test for a week.
 
 3-28-2012
 Adding back millis printing so we can tell what's going on/when.
 
 4-18-2012
 Unit works great at 9AM but they report the unit is continuing to hang. Removing GPS parsing doesn't seem to have made it better or worse. 
 
 I may need to go to the external MIDI unit.
 I have a new, non-IR amp to install. I forgot it this week but will bring it next.
 
 Write our own GPS parser - I am weary of crack_gps.
 Install non-IR amp
 Remove IR routines
 Use external MIDI box
 Install new main board power adapter. Original was 12V, install 9V
 Leave extra parts in red box, including microSD adapter.
 
 4-24-12
 Commiting code and eagle files to Github.
 
 To do:
 Removing IR code - done
 Log all error ridden data - done
 Check for errors from light controller (we normally just pass commands to it) - done
 
 4-25-12
 New amp installed. Boot time is much faster.
 PTCs installed.
 
 Hammering on the instrument button causes system reset. Removing the GPS causes the unit not to reset.
 I added some dog petting to the button. I believe there is a spot where the watch dog would reset the system when pounded fast enough.
 Should be fixed now. I also added error logging to various spots if we received odd data from the IR controller board. This should allow us
 to tell when and if it resets.
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

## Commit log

2012-04-25 Adding Eagle layout files
    [Ilumitunes-IR-Breakout-v10.brd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]
2012-04-25 Removed IR support from Master controller. Log all error ridden data. Check for errors from light controller.
    Added ToDo for PTCs on Master Controller.
    [Ilumitunes-Master-Controller-v11.brd, Ilumitunes-Master-Controller-v11.sch]
2012-05-13 Added more PTC and decoupling to string controller at breakout.
    [Ilumitunes-IR-String-Controller-v10.brd, Ilumitunes-IR-String-Controller-v10.sch, Ilumitunes-IR-String-Controller-v11.brd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]
2012-07-04 Updated IR controller to work with Arduino v1.0
    Not yet tested. Unsure if Av1.0 does anything weird with the microsecond
    delays or inline assembly.
2012-07-04 Updates logs. Added pull up to button on master. Added PTC and reset cap to IR controller.
    [Ilumitunes-IR-String-Controller-v13.brd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]
2012-07-04 Testing out the merge branch tool on new github windows.
    [Ilumitunes-IR-Breakout-v11.GBL, Ilumitunes-IR-Breakout-v11.GBO, Ilumitunes-IR-Breakout-v11.GBS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]
2012-07-15 Added a reset routine every 4 hours. Updated logs.
    [Illumitune_Main_Controller.ino]
2012-10-21 Illumitune is now stable. Updating logs.
    Illumitune has been stably running for a few months now. I believe the
    reset every four hours was the main fix. This was not possible before
    changing out the amp for a simple, solid-state, low cost solution
    ($20!). I hope you can learn something from all these trials and
    tribulations.
    From now on there will probably only be log updates as the code is
    pretty stable.
    [Illumitune_Main_Controller.ino]
2013-01-14 Added small breakout for IR receiver. Updated logs.
    Added a small breakout board for the IR receiver. This board has a
    mounting hole and a JST connector to make swapping IR receivers in/out a
    little easier.
    [IR-Receiver-v10.brd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]

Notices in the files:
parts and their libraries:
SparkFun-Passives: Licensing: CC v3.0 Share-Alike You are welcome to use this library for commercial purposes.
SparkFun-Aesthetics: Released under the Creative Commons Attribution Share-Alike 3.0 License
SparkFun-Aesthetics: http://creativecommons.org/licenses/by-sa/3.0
